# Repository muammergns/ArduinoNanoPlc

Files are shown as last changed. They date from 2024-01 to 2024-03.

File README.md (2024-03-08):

# Arduino Nano Plc
  indusrial arduino nano plc 8DI 8DO 1AO
 Tasarım amacı; kontrol panelli, 4 adet sensör ve 6 adet valf bağlanabilen kompak ve endüstriyel bir cihaz üretmek.

### Güç voltajı 24V Max 6A
8 dijital giriş PNP
8 dijital çıkış NPN
1 analog çıkış 0-10V
1 rs485 seri veriyolu Modbus RTU 8N1

### Besleme Voltajı
Güç girişi için önerilen voltaj 24V olarak belirlendi.
Yapılan testlerde 12-30V arası düzgün çalıştığı gözlemlendi.
PLC kartı maksimum 6A yük taşıyabilir. Eğer daha fazla bir yük gerekiyorsa anahtarlama elemanları ile (role gibi) yük karttan alınabilir.

### Dijital Girişler
4 adet PNP giriş sensör besleme voltajı klemenste bulunduğu için doğrudan bağlantı yapılabilir.
4 adet PNP giriş kontrol paneli buton bağlantıları için ayrıldı. (klemens grubu ayrı)

### Dijital Çıkışlar
6 adet NPN çıkış kontaktör, role, solenoid valf için besleme voltajı klemenste bulunduğu için direk bağlantı yapılabilir.
2 adet NPN çıkış kontrol paneli ikaz lambaları bağlantıları için ayrıldı. (klemens grubu ayrı)

### Analog Çıkış
1 adet 0-10V 12 bit analog çıkış programlanabilir.

### Seri Veriyolu
1 adet RS485 bağlantı ile Modbus RTU Master cihazlarla iletişim kurabilir.
Arduino nano'nun getirdiği kısıtlama nedeniyle haberleşme parametresi yalnızca 8N1 ayarlanabilir.
önerilen haberleşme hızı 9600 baud rate'dir. 115200 baud rate hızına kadar destekler.
250 word hafıza alanına kadar destekler ve tüm modbus adresleri aynı alana referans verir.
örneğin, holding register 400010 ile 300010 aynı adrese karşılık gelir.
veya, coil 10 ile input coil 10 aynı adrese karşılık gelir
son olarak ÖNEMLİ!!! coil 10 = input coil 10 = holding register 400000.10 = input register 300000.10 aynı adreslerdir.
tüm değerler REGS.h içinde uint16_t data[250]; dizisi ile tutulur.

### Kontrol Paneli
Start Butonu
Stop Butonu
Acil Stop Butonu
Ürün Sensörü

Yeşil İkaz Lambası
Kırmızı İkaz Lambası

### Çalışma Şekli
İlk enerjilendiğinde veya bir arıza durumunda sistem reset gereklidir.
Stop Butonuna 1 saniye basılı tutulduğunda sistem reset aktif olur.
Arıza durumunda pasif olur ve korumaya alır. Örneğin acil durdurma veya bir arıza koşulu eklenirse.
Yine arıza durumunda Kırmızı İkaz Lambası veya Buzzer sinyal verir.
Start Butonuna basıldığında üretim başlar ve Stop Butonu ile üretim durdurulur.
Üretim başladığında Yeşil İkaz Lambası sinyal verir.
Ürün Sensörü aslında bir döngülük otomatik hareketi başlatmak için tasarlandı ve sinyal kontrol panelinden alındı.
Bu bağlantılar yapıldıktan sonra;
4 adet dijital giriş PNP (3 kablolu sensörler direk bağlanabiliyor)
6 adet dijital çıkış NPN (2 kablo direk kontaktöre veya valfe bağlanabilir)
Bu kısım kartın PCB bağlantılarında detaylandırılacak.

Modbus kütüphanesi hakkında detaylı bilgi için ziyaret ediniz. 
https://github.com/smarmengol/Modbus-Master-Slave-for-Arduino

PlatformIO 
include hatalarını gidermek için .vscode\c_cpp_properties.json dosyasını kontrol edin

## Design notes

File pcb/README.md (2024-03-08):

# PCB tasarımı
Tasarımın tamamı EasyEDA üzerinden yapıldı.
Malzemeler seçilirken sadece delik boyutları ve yerleşime özen gösterildi.
Baskılar JLCPCB ile üretildi
EasyEDA ile proje import yaparak kendiniz de düzenleyebilir veya kontrol edebilirsiniz
Projeyle uğraşmak istemezseniz Gerber dosyasını herhangi bir pcb üreticiye teslim ederek kartları üretebilirsiniz.

Ayrıca PCB montaj yapabileceğiniz bir kutu tasarımı da projeye eklendi. Bunu 3D yazıcı ile üretip kullanabilirsiniz.

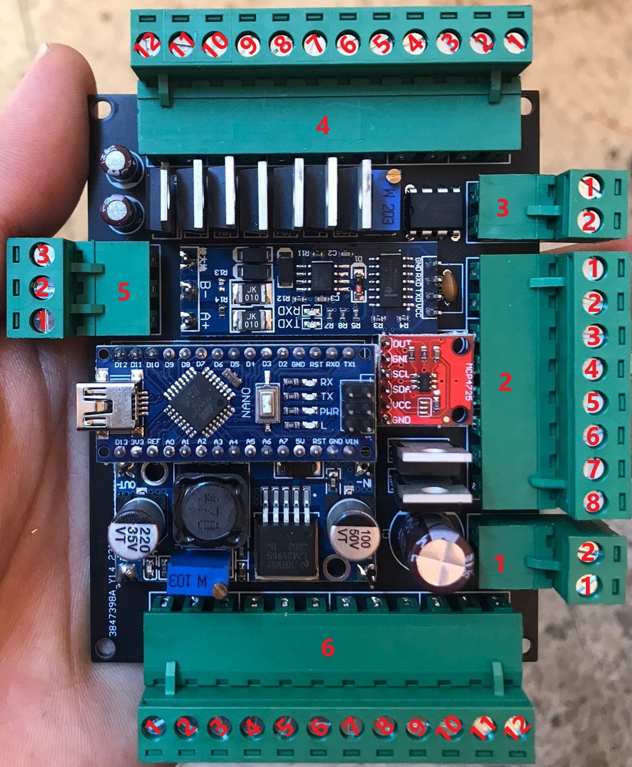
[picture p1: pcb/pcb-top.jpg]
PCB


## Klemens Bağlantıları
| 1.1 | 1.2 |
| :- | :- |
| Güç +24V | Güç 0V |

| 2.1 | 2.2 | 2.3 | 2.4 | 2.5 | 2.6 | 2.7 | 2.8 |
| :- | :- | :- | :- | :- | :- | :- | :- |
| HMI +24V | HMI 0V | Product IN | Emergency IN | Stop IN | Start IN | Lamp OUT | Buzzer OUT |

| 3.1 | 3.2 |
| :--- | :--- |
| 0-10V + | 0-10V - |

| 4.1 | 4.2 | 4.3 | 4.4 | 4.5 | 4.6 |
| :- | :- | :- | :- | :- | :- |
| OUT 1+ | OUT 1- | OUT 2+ | OUT 2- | OUT 3+ | OUT 3- |

| 4.7 | 4.8 | 4.9 | 4.10 | 4.11 | 4.12 |
| :- | :- | :- | :- | :- | :- |
| OUT 4+ | OUT 4- | OUT 5+ | OUT 5- | OUT 6+ | OUT 6- |

| 5.1 | 5.2 | 5.3 |
| :- | :- | :- |
| RS485 A | RS485 B | RS485 GND |

| 6.1 | 6.2  | 6.3 | 6.4 | 6.5  | 6.6 |
| :- | :- | :- | :- | :- | :- |
| Sensör+ | IN 1 | Sensör- | Sensör+ | IN 2 | Sensör- |

| 6.7 | 6.8  | 6.9 | 6.10 | 6.11 | 6.12 |
| :- | :- | :- | :- | :- | :- |
| Sensör+ | IN 3 | Sensör- | Sensör+ | IN 4 | Sensör- |

### Malzeme Listesi yakında..

### Ürün linkleri yakında..

### Dikkat edilmesi gerekenler
- Karta enerji vermeden önce arduino headerdan sökülmelidir. Voltaj regülatörü trimpot ile `9V` ayarlandıktan sonra arduino yerine takılabilir.
- Arduino headera takılıyken RS485-TTL dönüştürücü sinyalleri bozduğu için programlanamaz. Bu yüzden her program atılırken sökülmelidir.
- Programı yükledikten sonra 0-10V kalibre edilmelidir. 12bit olduğu için analog değere 4095 gönderilir. Ardından trimpot ile `10V` ayarlanır.

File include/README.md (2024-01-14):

Arduino modbus and rom configurator files

IO(uint8_t numberPin, uint8_t modePin)

IO(uint8_t numberPin, uint8_t modePin, unsigned int filterCount)

TMR(unsigned long* PT)

BITS(uint16_t *regs, uint8_t adress)

BITS(uint16_t *regs, uint8_t adress, int romadr)

FLOATS(uint16_t *regs, uint8_t adress)

FLOATS(uint16_t *regs, uint8_t adress, int romadr)

INTS(uint16_t *regs, uint8_t adress)

INTS(uint16_t *regs, uint8_t adress, int romadr)

LONGS(uint16_t *regs, uint8_t adress)

LONGS(uint16_t *regs, uint8_t adress, int romadr)

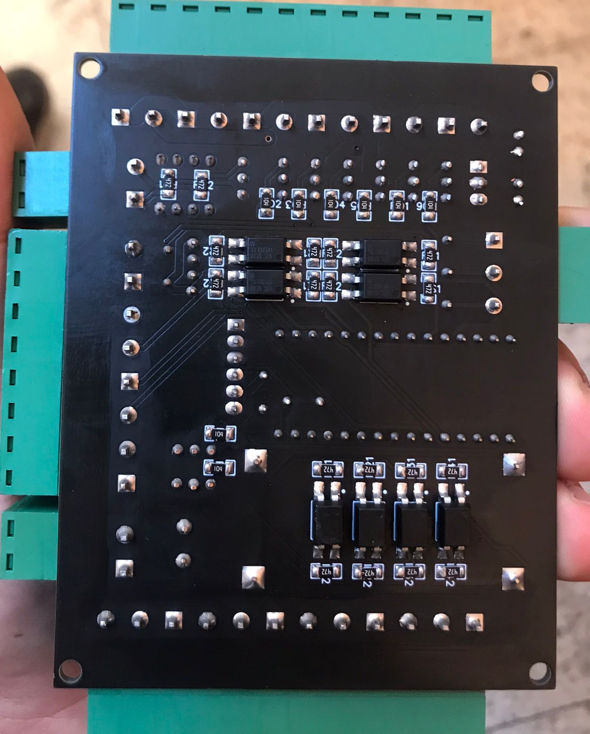
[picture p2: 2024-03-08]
pcb/pcb-bottom.jpg

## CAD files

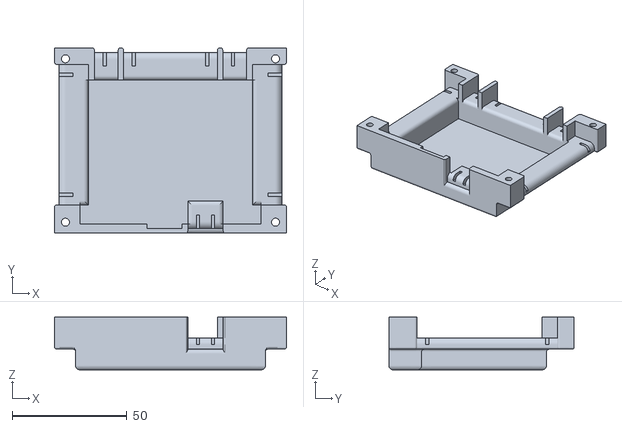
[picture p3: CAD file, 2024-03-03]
pcb/Top3dPrint.stl
101.0 x 80.7 x 23.0

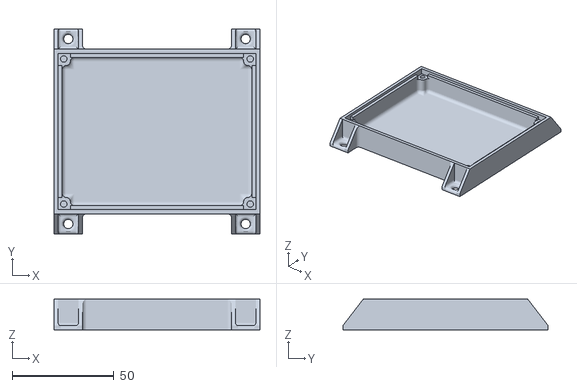
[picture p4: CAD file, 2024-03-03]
pcb/Bottom3dPrint.stl
101.0 x 100.7 x 15.0

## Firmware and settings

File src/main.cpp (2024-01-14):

#ifndef REG_H
#define REG_H
#include <REGS.h>
#endif
#include <Arduino.h>
#include <ModbusRtu.h>
#include <MachineControl.h>

Modbus hmi(1,Serial,0);
uint8_t mBusLenght = sizeof(data) / sizeof(int);

void setup() {
  Serial.begin( 9600, SERIAL_8N1 );
  hmi.start();
  analogBegin();
}

void loop() {
  hmi.poll(data, mBusLenght);
  machine_run();
}

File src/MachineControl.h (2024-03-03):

#pragma once
#ifndef REG_H
#define REG_H
#include <REGS.h>
#endif
#ifndef IO_H
#define IO_H
#include <IO.h>
#endif
#ifndef TMR_H
#define TMR_H
#include <TMR.h>
#endif

//NOTE - Temel süre ayarları
unsigned long millisecond;//arduino millis() fonksiyonunu her döngüde 1 defa çalıştırmak için değişken oluşturuldu
unsigned long m_buzzer_fault = 40;//arıza durumunda 4 saniye boyunca buzzer'ın sinyal vermesi için süre ayarı
unsigned long m_buzzer_info = 2;//reset yapıldığında eğer bir sorun yoksa buzzer 200ms'lik sinyal süre ayarı
unsigned long m_reset_button_delay = 10;//reset yapmak için stop butonuna 1 saniye basılıtutma süre ayarı
unsigned long m_machine_speed_interval = 600;//makinenin üretim hızını hesaplamak için 1 dakikalık döngü süre ayarı
int product_count_for_machine_speed = 0;//1 dakikanın sonunda kaç adet üretim yapıldığının tutulduğu değişken

//NOTE - Zamanlayıcıların tanımlanması
/**
 * TMR name(&[unsigned long TIME_REF]) TIME_REF birimi 100ms'dir
 * 2 = 200ms
 * 10 = 1 saniye
 * 40 = 4 saniye
 * 600 = 1 dakika
 * HMI ekranda Numeric Input oluşturulurken 1,0 şeklinde ayarlandığında kolaylık olması için bu şekilde ayarlandı.
 * @see TMR.h
 */
TMR tmr_buzzer_fault(&m_buzzer_fault), tmr_buzzer_info(&m_buzzer_info), tmr_reset_button_delay(&m_reset_button_delay);
TMR tmr_machine_speed_interval(&m_machine_speed_interval);

/**
 * @brief system_reset_control
 * reset ve acil durdurma kontrollerinin yapıldığı fonksiyon
 * döngü boyunca sürekli kontrol edilir.
 * stop butonu veya ekrandan gönderilen reset komutu ile arıza var mı kontrol eder
 * eğer bir sorun yoksa sistem aktif olur. sistem aktif değilse tüm çıkışlar durdurulur
 * VEYA(||) operatörü ile başka arıza durumları eklenebilir. 
 * Örneğin bir motorun arıza sinyali alınır ve bu sinyal geldiğinde sistem durdurulur.
 * Arıza bilgisinin reset anında false yapılması gerekir. Böylece arıza halen devam ediyorsa buzzer tekrar arıza sinyali üretebilir.
 */
void system_reset_control(){
    if (!system_reset_info.get())
    {
        if (system_reset_button.get() || tmr_reset_button_delay.ON(millisecond, !io_stop.get()))
        {
            system_reset_info.set(true);
            emergency_stop_info.set(false);
        }
    }
    if (emergency_stop_info.get() /* || veya diğerleri */)
    {
        system_reset_info.set(false);
    }
    emergency_stop_info.set(!io_emergency.get());
}

/**
 * @brief production_control
 * üretimin başlatılıp durdurulmasının kontrolü
 * arıza varsa üretim duracaktır
 * sistem hazırsa start stop butonları ile üretim kontol edilebilir
 */
void production_control(){
    if (system_reset_info.get() && (io_start.get() || production_start_button.get())) { production_info.set(true); }
    if (!system_reset_info.get() || !io_stop.get() || production_stop_button.get()) { production_info.set(false); }
    production_stop_info.set(!production_info.get());
}

/**
 * @brief buzzer_control
 * buzzer ya da kırmızı ikaz lambasının kontrolü
 * sadece timer kontrolleri için ayrılmış bir fonksiyon
 * arıza durumunda 4 saniye ve sorun yok ikazı için 200ms sinyalinin kontrolü
 */
bool buzzer_control(){
    bool wFault = false; bool wInfo = false;
    if (system_reset_info.get())
    {
        wInfo = true; wFault = false;
        tmr_buzzer_fault.IN(); tmr_buzzer_info.IN(millisecond);
        if (tmr_buzzer_info.Q(millisecond)) { wInfo = false; }
    }
    else
    {
        wFault = true; wInfo = false;
        tmr_buzzer_info.IN(); tmr_buzzer_fault.IN(millisecond);
        if (tmr_buzzer_fault.Q(millisecond)) { wFault = false; }
    }
    return wFault || wInfo;
}

/**
 * @brief work_control
 * manuel ve otomatik çalışacak cihazların kontrolü
 * üretim başlatıldığında manuel çıkışlar kesilir
 * manuel kontrole geçildiğinde otomatik çıkışları kesilir
 * üretimin durumuna göre çıkışların iletilmesi gerçekleştirilir
 * yine arıza durumunda tüm çıkışların kesilmesini burası kontrol eder
 */
void work_control(){
    bool production = production_info.get();
    if (!system_reset_info.get() || production)
    {//ÜRETİM VARSA DURDURULACAKLAR 
        manu_output_0_info.set(false);
        manu_output_1_info.set(false);
        manu_output_2_info.set(false);
        manu_output_3_info.set(false);
        manu_output_4_info.set(false);
        manu_output_5_info.set(false);
    }
    if (!system_reset_info.get() || !production)
    {//ÜRETİM YOKSA DURDURULACAKLAR
        auto_output_0_info.set(false);
        auto_output_1_info.set(false);
        auto_output_2_info.set(false);
        auto_output_3_info.set(false);
        auto_output_4_info.set(false);
        auto_output_5_info.set(false);
    }
    hmi_output_0_info.set(production ? auto_output_0_info.get() : manu_output_0_info.get());
    hmi_output_1_info.set(production ? auto_output_1_info.get() : manu_output_1_info.get());
    hmi_output_2_info.set(production ? auto_output_2_info.get() : manu_output_2_info.get());
    hmi_output_3_info.set(production ? auto_output_3_info.get() : manu_output_3_info.get());
    hmi_output_4_info.set(production ? auto_output_4_info.get() : manu_output_4_info.get());
    hmi_output_5_info.set(production ? auto_output_5_info.get() : manu_output_5_info.get());
}

/**
 * @brief io_control
 * fiziksel sinyallerin ekrana veya ekrandan gelen sinyallerin fiziksel çıkışlara iletilmesini kontrol eder
 * ayrıca analog çıkışın (bu durumda sürücü hızı örnek alınmış) iletildiği yer
 */
void io_control(){
    hmi_start_button_info.set(io_start.get());
    hmi_stop_button_info.set(io_stop.get());
    hmi_acil_button_info.set(io_emergency.get());
    hmi_product_sensor_info.set(io_product.get());

    hmi_input_0_info.set(io_input_0.get());
    hmi_input_1_info.set(io_input_1.get());
    hmi_input_2_info.set(io_input_2.get());
    hmi_input_3_info.set(io_input_3.get());
    
    io_output_0.put(hmi_output_0_info.get());
    io_output_1.put(hmi_output_1_info.get());
    io_output_2.put(hmi_output_2_info.get());
    io_output_3.put(hmi_output_3_info.get());
    io_output_4.put(hmi_output_4_info.get());
    io_output_5.put(hmi_output_5_info.get());

    writeAnalog(inverter_speed.get());
}
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
